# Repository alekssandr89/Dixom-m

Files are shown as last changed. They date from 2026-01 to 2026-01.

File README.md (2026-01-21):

# Dixom-m  
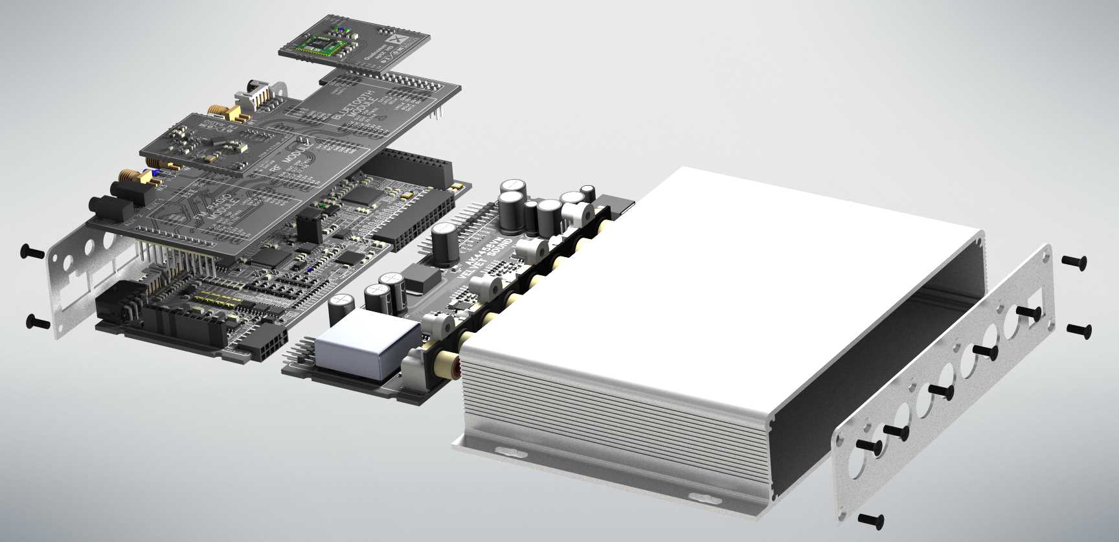
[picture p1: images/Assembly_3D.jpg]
Dixom-m Assembly 3D

## Цифровая модульная аудиоплатформа
<p align="center">
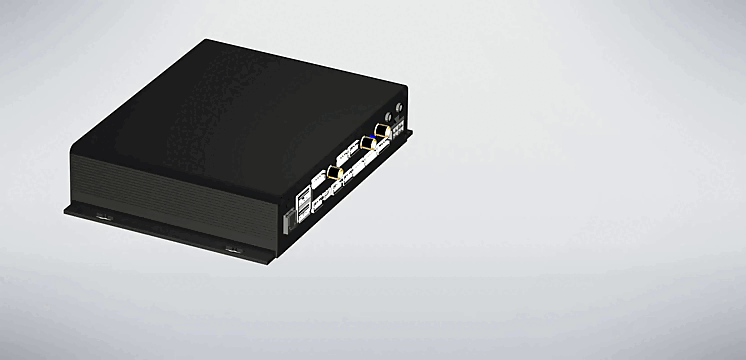
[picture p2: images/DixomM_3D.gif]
Dixom-m Assembly 3D
  
</p>

**Dixom-m** — это цифровая модульная аудиоплатформа, предназначенная в первую очередь для построения **кастомных автомобильных аудиосистем и автомагнитол** на базе **Android-планшетов и Android-устройств**. Платформа ориентирована на энтузиастов, разработчиков и интеграторов, которым требуется гибкая, расширяемая и качественная аудиоархитектура.

---

## Назначение платформы

Основная цель Dixom-m — предоставить аппаратную основу для создания **нестандартных Android-магнитол**, превосходящих по возможностям и качеству звучания серийные решения.

Платформа позволяет:
- использовать Android-планшет в качестве головного устройства (UI, навигация, мультимедиа);
- вынести аудиотракт в отдельные специализированные модули;
- масштабировать систему под конкретные требования проекта.

---

## Ключевая концепция

Dixom-m построена по **модульному принципу**, где каждый функциональный блок реализован в виде отдельного аппаратного модуля. Это обеспечивает:

- гибкость конфигурации;
- упрощённую модернизацию;
- возможность кастомизации под конкретный автомобиль и аудиосистему.

---

## Основные возможности

### Цифровая обработка аудиосигнала
- работа с цифровыми аудиопотоками;
- минимизация потерь качества;
- возможность интеграции DSP-алгоритмов.

### Модульная архитектура
- отдельные модули для:
  - аудиовходов и выходов;
  - усиления;
  - управления питанием;
  - коммутации и интерфейсов;
- возможность добавления новых модулей без переработки всей системы.

### Интеграция с Android
- совместимость с Android-планшетами и Android-устройствами;
- использование Android как центрального интерфейса управления;
- поддержка кастомных приложений и сервисов.

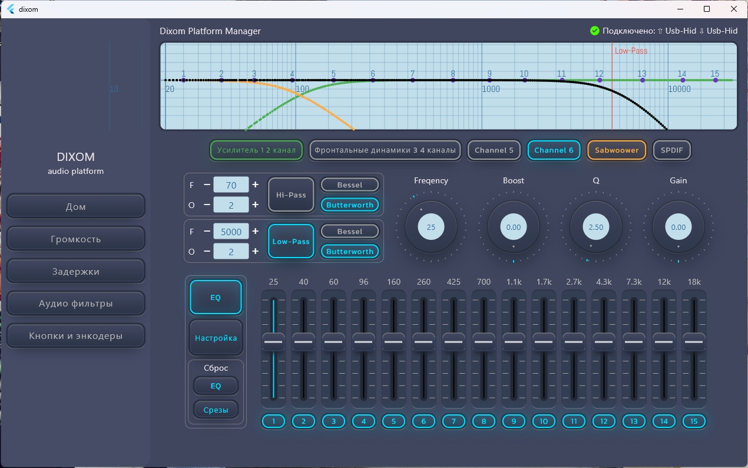
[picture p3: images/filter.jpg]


### Автомобильная направленность
- рассчитана на работу в автомобильной среде;
- возможность интеграции с бортовой сетью автомобиля;
- ориентация на качественный автозвук (SQ / SQL / кастомные проекты).

---

## Области применения

- кастомные Android-магнитолы;
- DIY-автозвук и инсталляции;
- экспериментальные аудиопроекты;
- прототипирование цифровых аудиосистем;
- мультимедийные автомобильные комплексы.

---

## Преимущества

- полная кастомизация под конкретный проект;
- независимость от готовых коммерческих магнитол;
- возможность постепенного расширения системы;
- ориентация на высокое качество звука;
- открытость к доработкам и развитию.

---

## Статус проекта

Проект **Dixom-m** находится в стадии активной разработки и развития.  
Архитектура, аппаратные модули и программная часть могут изменяться и дополняться.

---

## Цель проекта

Создание универсальной, масштабируемой и качественной аппаратной платформы для построения **современных автомобильных аудиосистем нового поколения** на базе Android.

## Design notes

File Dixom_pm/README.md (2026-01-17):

# dixom

A new Flutter project.

## Getting Started

This project is a starting point for a Flutter application.

A few resources to get you started if this is your first Flutter project:

- [Lab: Write your first Flutter app](https://docs.flutter.dev/get-started/codelab)
- [Cookbook: Useful Flutter samples](https://docs.flutter.dev/cookbook)

For help getting started with Flutter development, view the
[online documentation](https://docs.flutter.dev/), which offers tutorials,
samples, guidance on mobile development, and a full API reference.

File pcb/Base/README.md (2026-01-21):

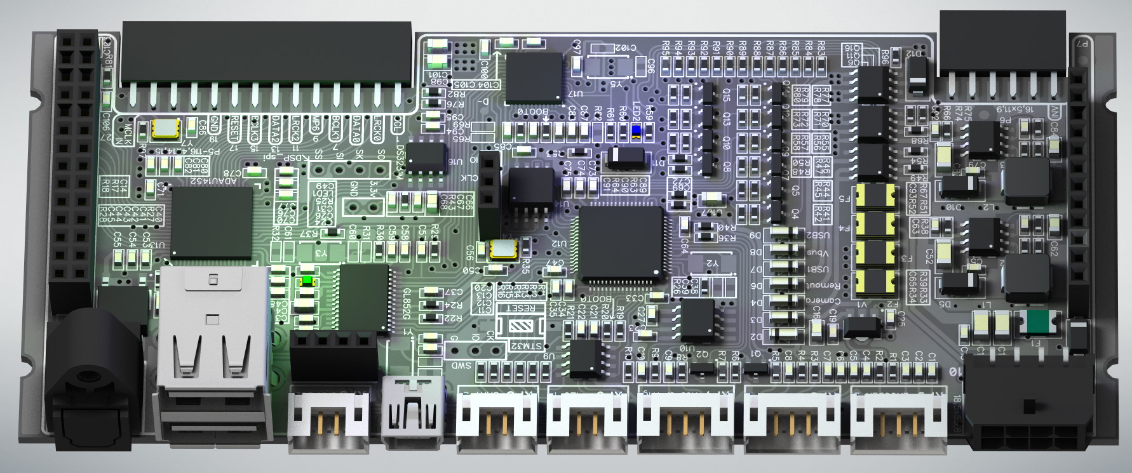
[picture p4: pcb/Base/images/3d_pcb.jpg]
3D PCB

**Рисунок 1 — 3D модель платы Dixom-M Base**

Для корректной сборки и запуска платформы необходимо приобрести все электронные компоненты, перечисленные в таблице № 1.

Рекомендуется закладывать резерв по пассивным компонентам в корпусе SMD 0603 (конденсаторы и резисторы), поскольку из-за их малых габаритов существует повышенный риск утери или повреждения в процессе ручного монтажа.

Компоненты, выделенные в таблице красным цветом, являются опциональными и не подлежат установке на базовую плату, соответственно их приобретение не требуется.
<details>
<summary><strong>Таблица 1 — Bill of Materials (BOM)</strong></summary>

<br>

| № | RefDes | Наименование | Корпус / Тип | Кол-во | Выводы |
|---|---|---|---|---|---|
| 1 | U9 | PCA82C250 | SOIC-8/150mil | 1 | 8 |
| 2 | U10 | 24LC256-I/SN | SOIC-8/150mil | 1 | 8 |
| 3 | U11 | GL852G-HHG12 | SOP-28/8.1x0.65 | 1 | 28 |
| 4 | U12 | STM32F405RGT6 | QFP-64/12x12x0.5 | 1 | 64 |
| 5 | U13 | ADAU1452WBCPZ | LFCSP-72 | 1 | 72 |
| 6 | U14 | W25Q80DVSSIG | SOIC-8/200mil | 1 | 8 |
| 7 | U15 | DS3231MZ | SOIC-8/150mil | 1 | 8 |
| 8 | U16 | STM32F411CEU6 | UFQFPN-48 (7x7) | 1 | 48 |
| 9 | V1 | HT7533-1 | SOT-89 | 1 | 3 |
|10 | V2, V3 | MP1584EN | SOIC-8EP/150mil | 2 | 8 |
|11 | D1, D5, D10–D12 | SS54B | SMB (DO-214AA) | 5 | 2 |
|12 | D2–D9 | LL4148 | LL-34 | 8 | 2 |
|13 | L1 | BCIHP0730-150M | IND 7×7×3 mm | 1 | 2 |
|14 | L2 | BCIHP0730-100M | IND 7×7×3 mm | 1 | 2 |
|15 | F1 | TLC-MSMD150/24 | 1812 | 1 | 2 |
|16 | F2 | TLC-MSMD110 | 1812 | 1 | 2 |
|17 | F3–F5 | TLC-MSMD110/24 | 1812 | 3 | 2 |
|18 | Q1, Q2, Q4, Q5, Q7–Q10, Q12–Q15 | BC817-40 | SOT-23 | 12 | 3 |
|19 | Q3 | STD2805T4 | DPAK-3 | 1 | 3 |
|20 | Q6, Q11, Q16 | AO4801 | SOIC-8/150mil | 3 | 8 |
|21 | Y4 | Q33310F70060700 (12 MHz) | SMD 3225-4P | 1 | 4 |
|22 | Y6 | SX7M24.576M20F30TNN | SMD 3225-4P | 1 | 4 |
|23 | Y7 | SX3M22.5792M20F30TNN | SMD 3225-4P | 1 | 4 |
|24 | LED1 | Зелёный светодиод | SMD 0603 | 1 | 2 |
|25 | LED2 | Синий светодиод | SMD 0603 | 1 | 2 |
|26 | C1, C2, C3, C5, C6, C7, C9, C10, C48, C53, C70, C80 | 10 nF | SMD 0603 | 12 | 2 |
|27 | C4, C8, C13, C19–C26, C28, C29, C33, C34, C37, C40, C42, C43, C45, C46, C49–C51, C54, C58, C59, C63, C64, C67, C71, C72, C74, C77–C79, C81, C85–C88, C91, C92, C94, C97, C103, C105 | 100 nF | SMD 0603 | 46 | 2 |
|28 | C14, C16, C30, C31, C62, C66, C84, C98, C101 | 22 µF 16 V | SMD 0805 | 9 | 2 |
|29 | C15, C22, C27, C35, C36, C44, C47, C55, C57, C68, C69, C73, C75, C76, C82, C89, C90, C95, C100, C104 | 1 µF | SMD 0603 | 20 | 2 |
|30 | C17, C18, C52, C83 | 22 µF 25 V | SMD 1206 | 4 | 2 |
|31 | C32 | 5.6 nF | SMD 0603 | 1 | 2 |
|32 | C41, C56, C65, C106 | 150 pF | SMD 0603 | 4 | 2 |
|33 | C93 | 220 pF | SMD 0603 | 1 | 2 |
|34 | R1, R3, R5, R7, R9, R10, R12, R21, R29, R41, R43, R44, R46, R48–R50, R54, R55, R57, R68, R70, R72, R74, R75, R77, R79, R96 | 10 kΩ | SMD 0603 | 27 | 2 |
|35 | R2, R4, R6, R8, R12–R16, R19, R20, R23, R24, R26, R35, R37, R42, R45, R47, R56, R58, R61, R71, R73, R78, R80, R81, R83–R88, R91, R97 | 100 Ω | SMD 0603 | 36 | 2 |
|36 | R11 | 120 Ω | SMD 0603 | 1 | 2 |
|37 | R17, R18, R76, R82, R90, R93, R95 | 2.2 kΩ | SMD 0603 | 7 | 2 |
|38 | R22, R25, R28, R36, R40, R53, R59, R60, R63, R64 | 1 kΩ | SMD 0603 | 10 | 2 |
|39 | R27 | 4.3 kΩ | SMD 0603 | 1 | 2 |
|40 | R33 | 20 kΩ | SMD 0603 | 1 | 2 |
|41 | R34 | 100 kΩ | SMD 0603 | 1 | 2 |
|42 | R38, R66 | 200 kΩ | SMD 0603 | 2 | 2 |
|43 | R39 | 3.9 kΩ | SMD 0603 | 1 | 2 |
|44 | R51 | 47 kΩ | SMD 0603 | 1 | 2 |
|45 | R52 | 68 kΩ | SMD 0603 | 1 | 2 |
|46 | R67, R89, R92, R94 | 15 kΩ | SMD 0603 | 4 | 2 |
|47 | CON1, CON2 | DS1023-2×14SF11 | P=2.54 mm | 2 | 28 |
|48 | CON6 | A2541HWV-3P | P=2.54 mm | 1 | 3 |
|49 | CON7 | C36191 | P=2.54 mm | 1 | 12 |
|50 | CON8 | A2541HWV-12P | P=2.54 mm | 1 | 12 |
|51 | CON9 | A2541HWV-4P | P=2.54 mm | 1 | 4 |
|52 | XP1 | PLR135/T9 | Through Hole | 1 | 3 |
|53 | XP2 | 907-112A1012D10200 | Plugin | 1 | 8 |
|54 | XP3, XP5, XP6 | S4B-PH-K-S | Push-Pull, P=2 mm | 3 | 4 |
|55 | XP4 | 920-462A2021D10102 | Plugin | 1 | 5 |
|56 | XP7–XP9 | S5B-PH-K-S | Push-Pull, P=2 mm | 1 | 5 |
|57 | XP10 | 43045-1200 | Micro-Fit | 1 | 8 |

</details>

Базовая плата аудио платформы Dixom-m выполнена на четырёхслойной печатной плате: верхний слой, два внутренних и нижний. Конструкция платы предусматривает размещение всех компонентов исключительно на верхней стороне, что значительно упрощает монтаж и последующую отладку устройства.

# Этапы сборки базовой платы аудио платформы Dixom-m

Процесс сборки базовой платы необходимо разделить на четыре этапа:

### Этап A — Монтаж и тестирование источников питания
- Необходимы напряжения **+3.3 В** и **+5 В**.
- Используются DC-DC преобразователи **MP1584EN** с регулировкой через сопротивления.
- Важно избегать повышения напряжения на линиях из-за ошибок или бракованных компонентов.
- Соберите и настройте источники питания.
- Проверьте стабильность +3.3 В и +5.0 В при входе 9–20 В.

### Этап B — Монтаж микросхем, микроконтроллеров и SMD-компонентов
### Этап C — Загрузка прошивок в микроконтроллеры
### Этап D — Комплексное тестирование собранной платы.
---

> **Важно:**  
> Устанавливать разъёмы и соединители следует только после успешного тестирования.  
> Ранний монтаж может осложнить замену неисправных компонентов во время отладки.

## A. Монтаж и тестирование источников питания

Для сборки DC-DC источников питания необходимы компоненты, перечисленные в таблице №2.  
На рисунке ниже зелёной областью схематически показано расположение этих компонентов.

Для подачи питания необходимо припаять системный разъём **XP10**.

Компоненты, выделенные красной зоной, на данном этапе устанавливать не нужно,  
за исключением резистора **R59** (SMD 0603, 1 кОм), который находится в красной зоне,  
он необходим для запуска DC-DC преобразователей.

После загрузки прошивки запуском и остановкой источников питания будет управлять микроконтроллер.
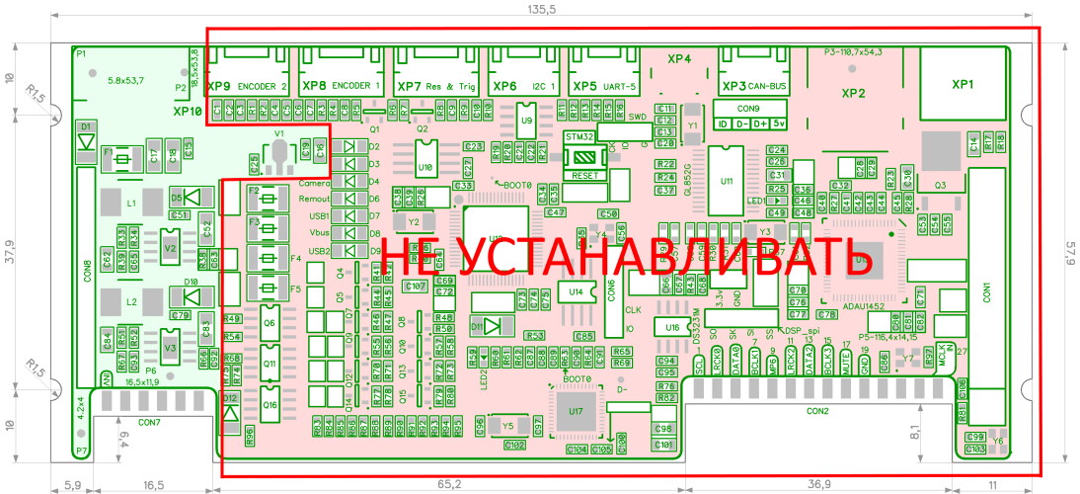
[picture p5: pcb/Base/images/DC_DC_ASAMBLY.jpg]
Рисунок 2 — Пайка источников питания

**Рисунок 2 — Пайка источников питания**

Для удобства ниже приведён список компонентов источников питания (эти позиции также присутствуют в Таблице 1).
<details>
<summary><strong>Таблица компонентов источника питания</strong></summary>

<br>

| №  | Обозначение | Наименование | Корпус | Кол-во | Выводы |
|-----|---|---|---|---|---|
| 1 | V1 | HT7533-1 | SOT89 | 1 | 3 |
| 2 | V2, V3 | MP1584EN | SOIC-8EP/150mil | 2 | 8 |
| 3 | D1, D5, D10 | SS54B | SMB(DO-214AA) | 3 | 2 |
| 4 | L1 | BCIHP0730-150M | IND 7*7*3mm | 1 | 2 |
| 5 | L2 | BCIHP0730-100M | IND 7*7*3mm | 1 | 2 |
| 6 | F1 | TLC-MSMD150/24 (24V 1.5A) | 1812 | 1 | 2 |
| 7 | C19, C25, C51, C63, C79, C92 | 100nF | SMD 0603 | 6 | 2 |
| 8 | C16, C62, C84 | 22uF 16V | SMD 0805 | 2 | 2 |
| 9 | C15 | 1uF | SMD 0603 | 1 | 2 |
| 10  | C65 | 150pF | SMD 0603 | 1 | 2 |
| 11  | C17, C18, C52, C83 | 22uF 25V | SMD 1206 | 4 | 2 |
| 12  | C93 | 220pF | SMD 0603 | 1 | 2 |
| 13  | R17, R18, R76, R82, R90, R93, R95 | 2.2kOm | SMD 0603 | 7 | 2 |
| 14  | R22, R25, R28, R36, R40, R53, R59, R60, R63, R64 | 1kOm | SMD 0603 | 10 | 2 |
| 15  | R33 | 20kOm | SMD 0603 | 1 | 2 |
| 16  | R34 | 100kOm | SMD 0603 | 1 | 2 |
| 17  | R38, R66 | 200kOm | SMD 0603 | 2 | 2 |
| 18  | R39 | 3.9kOm | SMD 0603 | 1 | 2 |
| 19  | R51 | 47kOm | SMD 0603 | 1 | 2 |
| 20  | R52 | 68kOm | SMD 0603 | 1 | 2 |
| 21  | R67 | 15kOm | SMD 0603 | 4 | 2 |
| 22  | XP10 | 43045-1200 | Micro Fit | 1 | 8 |

</details>

После завершения монтажа компонентов подайте напряжение в диапазоне от 9 до 20 В.  
Рекомендуется использовать лабораторный источник питания и проверить стабильность выходных напряжений по всему диапазону входных значений.

В первую очередь измерьте напряжение на конденсаторе **C16** — оно должно быть ровно **+3.3 В**.

Далее проверьте наличие напряжения на разъёме **CON2**. Здесь должны присутствовать напряжения **+3.3 В** и **+5.0 В**.  
Допустимые отклонения:  
- для +3.3 В — от 3.1 В до 3.4 В  
- для +5.0 В — от 4.7 В до 5.2 В  

Если напряжения выходят за эти пределы, необходимо найти и устранить причину.

Если на выходе DC-DC модулей (разъём CON2) напряжение отсутствует, проверьте наличие +3.3 В на резисторе **R59** с обеих сторон — он отвечает за включение преобразователей.  
Если напряжение на резисторе есть, проведите дополнительные проверки цепей вокруг микросхем MP1584 для выявления причины неисправности.

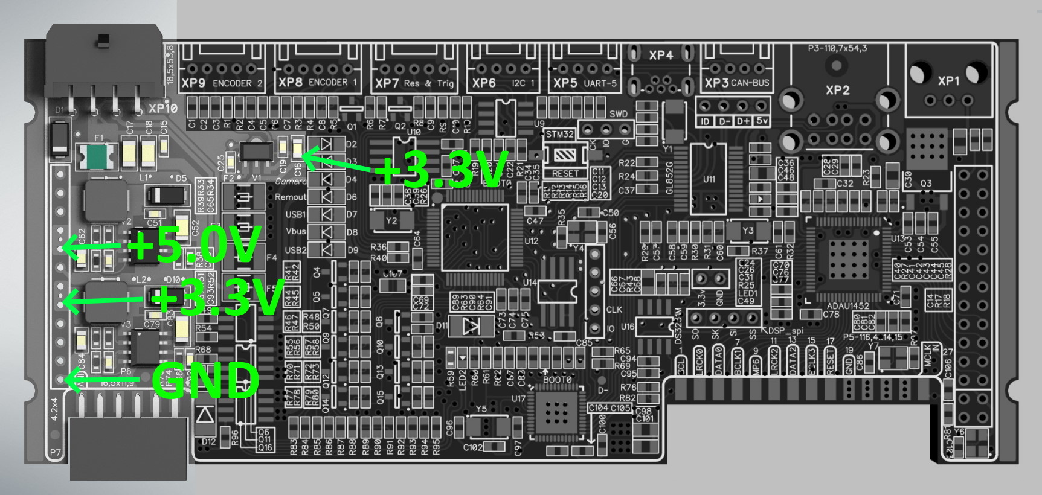
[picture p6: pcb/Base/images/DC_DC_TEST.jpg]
Рисунок 3 — Тестирование источников питания

**Рисунок 3 — Тестирование источников питания**

## B. Монтаж микросхем, микроконтроллеров и SMD-компонентов

После тщательной проверки всех напряжений и подтверждения их соответствия требованиям, можно приступать к монтажу остальных SMD-компонентов.

Ниже представлена схема расположения компонентов, а в таблице №1 — список компонентов с их позициями.  
В таблице компоненты, которые на данном этапе устанавливать не нужно, выделены красным цветом.  

Для удобства поиска компонентов в таблице доступен фильтр.

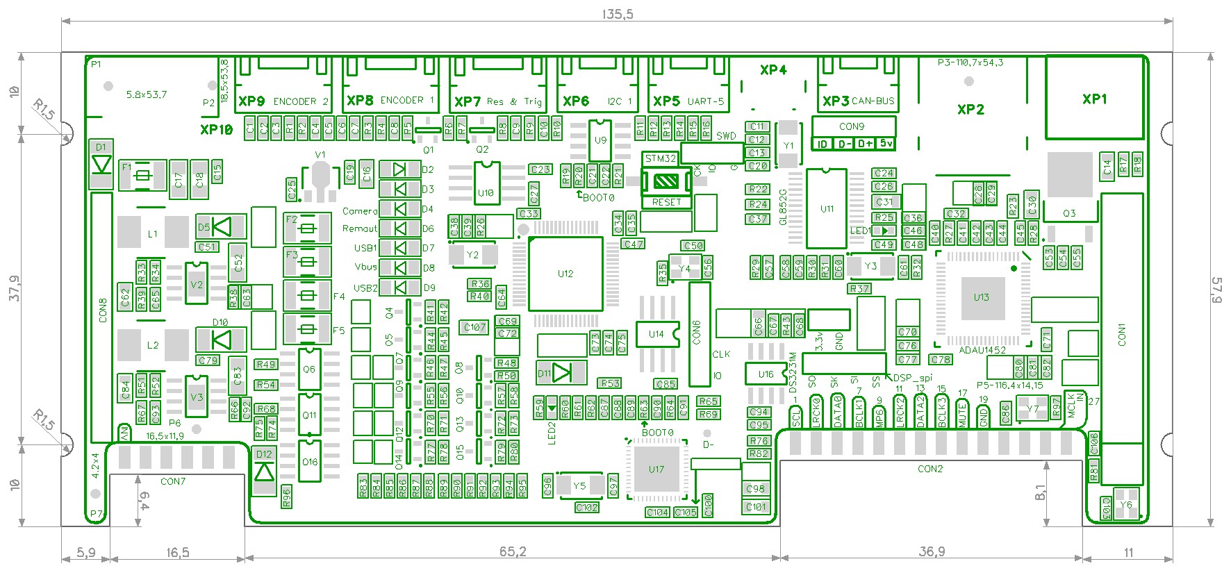
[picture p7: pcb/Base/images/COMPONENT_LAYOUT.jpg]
Рисунок 4 — Слой с компонентами

**Рисунок 4 — Слой с компонентами**
На данном этапе рекомендуется установить только минимальное количество разъёмов:  
основной разъём питания, MiniUSB-разъём и два соединителя — **CON2** и **CON7** для подключения ЦАП.  

Такой подход обусловлен тем, что при возникновении неисправностей в процессе загрузки прошивок и тестирования перепайка компонентов может занять много времени и потребовать усилий.  
Кроме того, использование паяльного фена повышает риск повреждения разъёмов и соединителей.

Ниже приведён рисунок, иллюстрирующий внешний вид печатной платы на данном этапе.

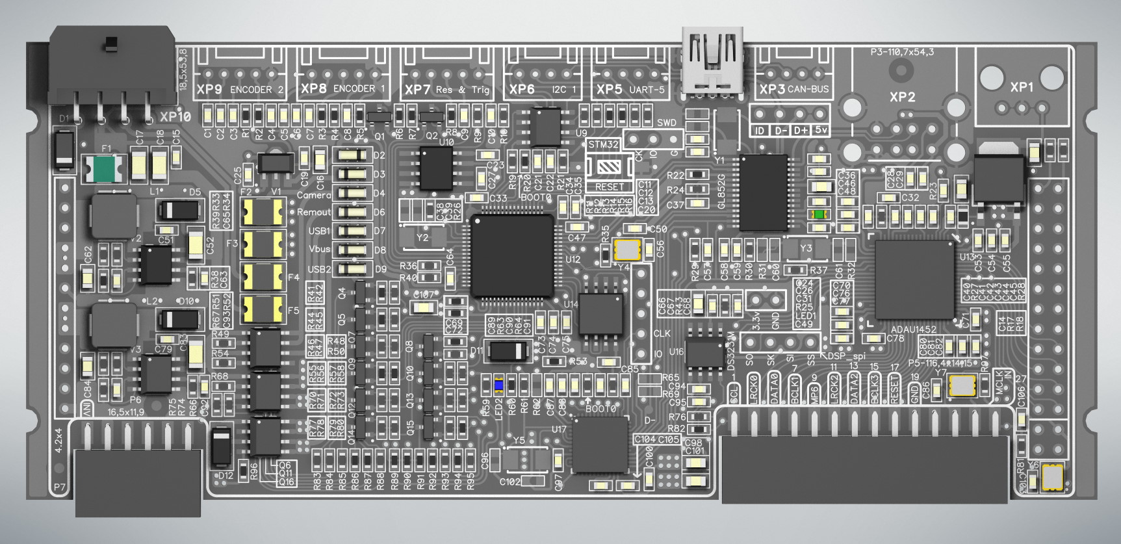
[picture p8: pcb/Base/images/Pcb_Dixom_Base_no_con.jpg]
Рисунок 5 — Плата без разъёмов

**Рисунок 5 — Плата без разъёмов**

## С Загрузка прошивок в микроконтроллеры и обновление

Для полноценной работы аудио платформы необходимо загрузить две прошивки:  
- одну в звуковую карту **STM32F411CEU6**,  
- вторую — в базовый микроконтроллер **STM32F405RGT6**.  

Существует два способа загрузки прошивок:  
1. Без программатора — через USB-кабель.  
2. С использованием программатора **ST-Link V2**, подключаясь к портам программирования SWD.

Для загрузки прошивок необходимо скачать соответствующие программы и файлы:  
- **Sound Bootloader** — включает загрузчик и основную прошивку звуковой карты.  
- **Base Bootloader** — содержит только загрузчик основного контроллера.

Чтобы загрузить основную прошивку:  
1. Сначала загрузите загрузчик в микроконтроллер **STM32F405RGT6**.  
2. Подключите аудио платформу к компьютеру через USB-кабель.  
3. Запустите программу **DixomPM**.  
4. Перейдите на вкладку **«Информация»**, нажмите кнопку **«Проверить наличие обновлений»** и загрузите обновление.  

> Для обновления требуется подключение к интернету.

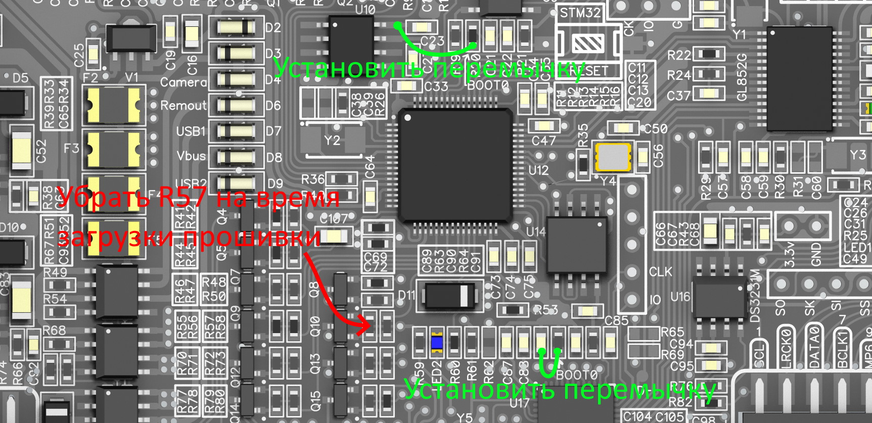
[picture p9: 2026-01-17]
pcb/Base/images/Pcb_Dixom_Base_dfu.jpg

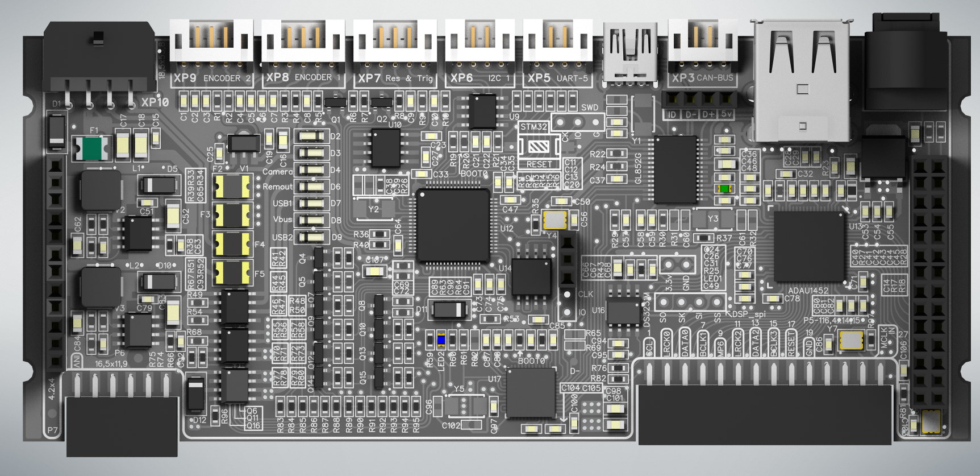
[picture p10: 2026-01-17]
pcb/Base/images/Pcb_Dixom_Base_Top.jpg

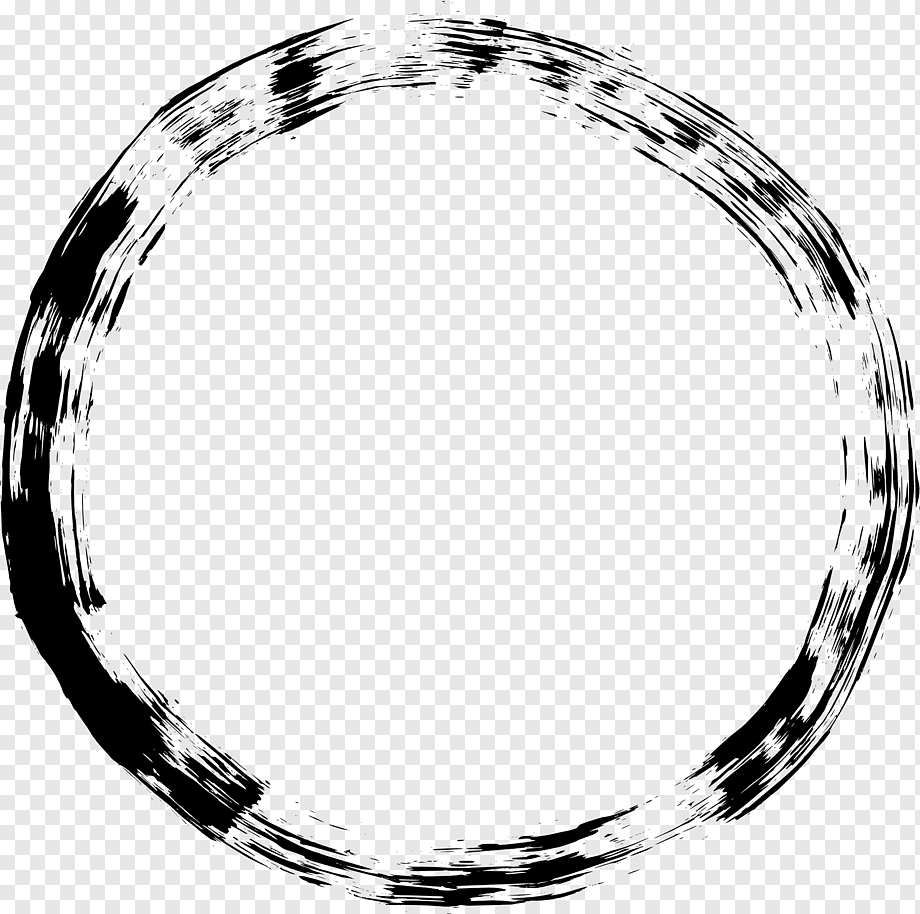
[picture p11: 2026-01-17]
Dixom_pm/assets/images/jpg/r1.png

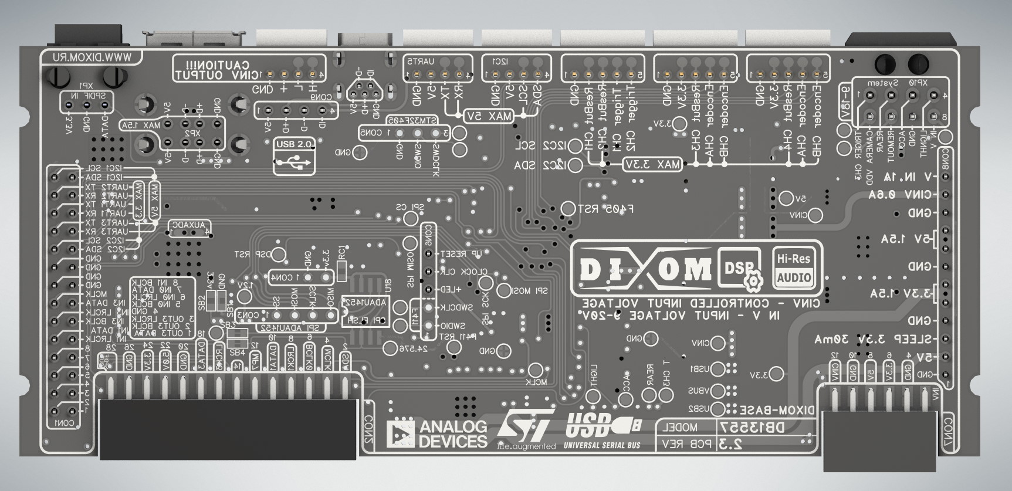
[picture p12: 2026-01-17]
pcb/Base/images/Pcb_Dixom_Base_Bottom.jpg

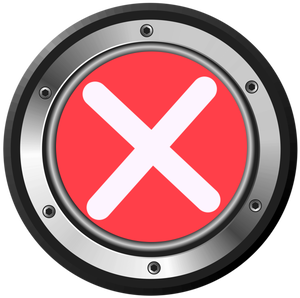
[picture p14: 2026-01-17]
Dixom_pm/assets/images/png/speakerMute.png

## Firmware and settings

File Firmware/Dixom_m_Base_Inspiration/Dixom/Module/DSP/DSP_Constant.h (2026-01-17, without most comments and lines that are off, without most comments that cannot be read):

#define __DSP_CONSTANT_H__
#include <Constants.h>
#define EQ_                         "EQ "
#define STATUS_EQ_                  "STATUS EQ "
#define CROSS_                      "CROSS "
#define PRESET_EQ_                  "PRESET EQ "
#define PRESET_CROSS_               "PRESET CROSS "
#define VOL_                        "VOL "
#define DELAY_                      "DELAY "
#define SOURCE_                     "SOURCE "
#define INVERT_                     "INVERT "
#define BTN_                        "BTN "
#define SETTINGS_                   "SETTINGS "
#define TIMER_                      "TIMER "
#define PHATSTEREO_                 "PHATSTEREO "
#define FILTR                       "FILTR"
#define ALL                         "ALL"
#define DATA_LENGTH_20            20
#define DATA_LENGTH_12            12
#define DATA_LENGTH_4             4
#define CONV_FLOAT                0.01
#define CONV_INT                  100
#define DacVolum                  0
#define MasterVolum               10
#define COUNT_USER_PRESET         4  //3 user preset + 1 main
#define PresetOff                 0
#define PresetUser1               1
#define PresetUser2               2
#define PresetUser3               3
#define PresetUser4               4
#define PresetUser5               5
#define PresetFlat                6
#define PresetBass                7
#define PresetBassExtreme         8
#define PresetBassAndHigh         9
#define PresetHigh                10
#define PresetClassic             11
#define PresetDancing             12
#define PresetRock                13
#define PresetTehno               14
#define PresetSpeaker             15
#define PresetLive                16
#define PresetMedium              17
#define PresetSoft                18
#define PresetSoftBass            19
#define PresetSoftHigh            20
#define GAIN_MIN                  -20
#define GAIN_MAX                  10
#define UNIQ_ELEM_CH_QE            15
typedef enum
{
	SoursUsb             =0,
	SoursBluetoooth      =1,
	SoursAux             =2,
	SoursRadio           =3,
	SoursSpdif           =4,
	SoursMic             =5
}TDE_SoundzSource;
typedef enum
{
	General_EQ =0,
	CH1        =1,
	CH2        =2,
	CH3        =3,
	CH4        =4,
	CH5        =5,
	CH6        =6,
	CH7        =7,
	CH8        =8,
	CH9        =9,
	CH10       =10,
	CH11       =11,
	CH12       =12,
	SPDIF_L    =13,
	SPDIF_R    =14
}TDE_AudioChanel;
typedef enum
{
	Band1 =0,
	Band2 =1,
	Band3 =2,
	Band4 =3,
	Band5 =4,
	Band6 =5,
	Band7 =6,
	Band8 =7,
	Band9 =8,
	Band10 =9,
	Band11 =10,
	Band12 =11,
	Band13 =12,
	Band14 =13,
	Band15 =14,
	Band16 =15,
	Band17 =16,
	Band18 =17,
	Band19 =18,
	Band20 =19,
	Band21 =20,
	Band22 =21,
	Band23 =22,
	Band24 =23,
	Band25 =24,
	Band26 =25,
	Band27 =26,
	Band28 =27,
	Band29 =28,
	Band30 =29
}TDE_EqBandNum;
typedef enum
{
	FILTER_OFF           =0,//GOOD
	PEAK                 =1,//GOOD
	LOWPASS              =2,//GOOD
	HIGHPASS             =3,//GOOD
	BUTTERWORTH_LP       =4,//GOOD
	BUTTERWORTH_HP       =5,//GOOD
	BESSEL_LP            =6,//GOOD
	BESSEL_HP            =7,//GOOD
	LOWPASS_FIRST        =8,//GOOD
	HIGHPASS_FIRST       =9,//GOOD
	LOW_SHELF            =10,//GOOD
	HIGH_SHELF           =11,//GOOD
	LINKWITZ_RILEY_HP    =12,//NO GOOD
	LINKWITZ_RILEY_LP    =13,//NO GOOD
	BANDPASS             =14,//NO GOOD
	BANDSTOP             =15//NO GOOD
}TDE_FilterType;
typedef enum
{
	High_Pass =0,
	Low_Pass  =1
}TDE_CrossoverFilterType;
typedef enum
{
	Main_Preset   =0,
	User_preset1  =1,
	User_preset2  =2,
	User_preset3  =3
}TDE_Preset;
typedef enum
{
	VolumControlOnDAC            =0,
	VolumControlOnDSP            =1,
	VolumControlOnLoudness       =2
}TDE_VolumeControlMode;
#define SAMPLE_RATE_22050         22050
#define SAMPLE_RATE_32000         32000
#define SAMPLE_RATE_44100         44100
#define SAMPLE_RATE_48000         48000
#define SAMPLE_RATE_88200         88200
#define SAMPLE_RATE_96000         96000
#define SAMPLE_RATE_192000        192000
#define SAMPLE_RATE_348000        348000
#define SAMPLE_RATE_768000        768000
#define GAIN_CONST                0
#define CrossoverCount            14
#define EqualizerCount            15
#define DELAY_SAMPLE              1440
#define FILTER_EQ_SOURCE_Q_DEF    71    //*0,01
#define FILTER_CROSS_Q_DEF        71    //*0,01
#define FILTER_EQ_CH_Q_DEF        250   //*0,01
#define FILTER_TYPE_DEF           1
#define FILTER_FREQ_DEF           20
#define FILTER_BOOST_DEF          0      //*0,01
#define FILTER_ORDER_DEF          2
#define FILTER_EQ_ONOFF_DEF       ON
#define FILTER_CROSS_ONOFF_DEF    OFF
#define FILTER_POINT_DEF          0
#define DEFAULT_INVERT            0
#define DEFAULT_DELAY             0     //*0,01
#define DEFAULT_GAIN              0
#define NUM_ELEM_EQ_GENERAL      30
#define NUM_ELEM_DELAY           14
#define NUM_ELEM_INVERT          26
#define NUM_ELEM_PHATSTEREO      6
#define NUM_ELEM_WIDESTEREO      6
#define NUM_ELEM_SUPPERBASS      6
#define NUM_ELEM_VOL             248
#define NUM_ELEM_FILTR           270
#define NUM_ELEM_EQ_CENTR        30
#define NUM_ELEM_CROSSOVER       14
#define NUM_ELEM_CROSSOVER_TYPE  2
#define NUM_ELEM_EQ_CH           14
#define NUM_ELEM_GROUP           8
#define NUM_PRESET               3
#define NUM_ELEM_EQ_CH_BAND      15
#define NUM_ELEM_EQ_SOURCE_BAND  5
#define NUM_ELEM_DAC             13
#define NUM_ELEM_LOUDNESS        6
#define NUM_ELEM_LIMITER         14
#define NUM_ELEM_GAIN            14
#define NUM_ELEM_GROUP_NAME      7
#define NUM_ELEM_GROUP_DELAY     7
#define NUM_ELEM_LVL_DETECTED    64
#define NUM_ELEM_GRAPHIC_EQ      32
#define NUM_ELEM_DSP_SETTINGS    64
#define NUM_ELEM_SOURCE          6
#define NUM_ELEM_VOL_EEPROM      50
#define INVERT_MIN                0
#define INVERT_MAX                1
#define DELAY_MAX                 1000
#define DELAY_MIN                 0
#define VOL_MAX                   60
#define VOL_MIN                   0
#define FREQ_MAX                  22000
#define FREQ_MIN                  20
#define Q_MAX                     3000     //*0.01 = 30.00
#define Q_MIN                     5        //*0.01 = 00.05
#define BOOST_MAX                 2000     //*0.01 = 20.00
#define BOOST_MIN                 -2000    //*0.01 =-20.00
#define NAME_MAX_LEN              48
#define SBASSFREQ_MIN             20
#define SBASSFREQ_MAX             500
#define SBASSLVL_MIN              1
#define SBASSLVL_MAX              30
#define SBASSINTESIV_MIN          1
#define SBASSINTESIV_MAX          30
#define NO_GROUP                  255
#define ORDER_MAX                 10
#define ORDER_MIN                 1
#define SOUND_DELAY_MAX           3000
#define SOUND_DELAY_MIN           0
#define WIDESTEREO_MIN            0
#define WIDESTEREO_MAX            20
#define DEF_SINGEN_FREQ           1500
#define DEF_SINGEN_PHASE          0
#define EQ_GENERAL                0
#define FILTR_CH1                 1
#define FILTR_CH2                 2
#define FILTR_CH3                 3
#define FILTR_CH4                 4
#define FILTR_CH5                 5
#define FILTR_CH6                 6
#define FILTR_CH7                 7
#define FILTR_CH8                 8
#define FILTR_CH9                 9
#define FILTR_CH10                10
#define FILTR_CH11                11
#define FILTR_CH12                12
#define FILTR_SPDIFL              13
#define FILTR_SPDIFR              14
#define CrossCH1                  15
#define CrossCH2                  16
#define CrossCH3                  17
#define CrossCH4                  18
#define CrossCH5                  19
#define CrossCH6                  20
#define CrossCH7                  21
#define CrossCH8                  22
#define CrossCH9                  23
#define CrossCH10                 24
#define CrossCH11                 25
#define CrossCH12                 26
#define CrossSPDIFL               27
#define CrossSPDIFR               28
#define CROSS_ORDER_1             1
#define CROSS_ORDER_2             2
#define CROSS_ORDER_3             3
#define CROSS_ORDER_4             4
#define CROSS_ORDER_5             5
#define CROSS_ORDER_6             6
#define CROSS_ORDER_7             7
#define CROSS_ORDER_8             8
#define CROSS_ORDER_9             9
#define CROSS_ORDER_10            10
#define MaxVolumUsb               0
#define MaxVolumBluetooth         1
#define MaxVolumAux               2
#define MaxVolumRadio             3
#define MinVolumMic               4
#define MinVolumUsb               5
#define MinVolumBluetooth         6
#define MinVolumAux               7
#define MinVolumRadio             8
#define MinVolumSpdif             9
#define VolumUsb                  11
#define VolumBluetooth            14
#define VolumAux                  17
#define VolumRadio                20
#define VolumSpdif                23
#define VolumSoursMic             126
#define VolumGroup1               29
#define VolumGroup2               32
#define VolumGroup3               35
#define VolumGroup4               38
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

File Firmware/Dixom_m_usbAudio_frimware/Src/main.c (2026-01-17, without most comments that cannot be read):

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
/* Includes ------------------------------------------------------------------*/
#include "main.h"

/* USER CODE BEGIN Includes */
#include "usbd_audio_core.h"
#include "usbd_usr.h"
#include "usb_conf.h"
#include "usb_core.h"
#include "SoundMenu.h"
/* USER CODE END Includes */

I2C_HandleTypeDef hi2c1;
DMA_HandleTypeDef hdma_i2c1_rx;
DMA_HandleTypeDef hdma_i2c1_tx;

I2S_HandleTypeDef hi2s2;
DMA_HandleTypeDef hdma_spi2_tx;

TIM_HandleTypeDef htim2;

void SystemClock_Config(void);
static void MX_GPIO_Init(void);
static void MX_DMA_Init(void);
static void MX_I2C1_Init(void);
static void MX_I2S2_Init(void);
static void MX_TIM2_Init(void);
static void MX_NVIC_Init(void);
/* USER CODE BEGIN 0 */

static void Sound_MX_TIM2_Init(void);
#define APPLICATION_ADDRESS    0x08004000

__ALIGN_BEGIN USB_OTG_CORE_HANDLE  USB_OTG_dev __ALIGN_END;
/* USER CODE END 0 */

/**
  * @brief  The application entry point.
  * @retval int
  */
int main(void)
{
  /* USER CODE BEGIN 1 */
	__disable_irq();
	SCB->VTOR = APPLICATION_ADDRESS;
	__enable_irq();
  /* USER CODE END 1 */

  /* MCU Configuration--------------------------------------------------------*/

  /* Reset of all peripherals, Initializes the Flash interface and the Systick. */
  HAL_Init();

  /* Configure the system clock */
  SystemClock_Config();

  /* Initialize all configured peripherals */
  MX_GPIO_Init();
  MX_DMA_Init();
  MX_I2C1_Init();
  MX_I2S2_Init();
 // MX_TIM2_Init();

  /* Initialize interrupts */
  MX_NVIC_Init();
  /* USER CODE BEGIN 2 */
  HAL_I2S_MspInit(&hi2s2);

  Sound_MX_TIM2_Init();

  TIM2->CR1 |= (uint32_t)TIM_CR1_CEN;

  Init_Sound_Param();

  USBD_Init(&USB_OTG_dev,
 	            USB_OTG_FS_CORE_ID,
 	            &USR_desc,
 	            &AUDIO_cb,
 	            &USR_cb);

  I2C_1_START_IRQHandler();

  /* USER CODE END 2 */

  /* Infinite loop */
  /* USER CODE BEGIN WHILE */
  while (1)
  {
    /* USER CODE END WHILE */

    /* USER CODE BEGIN 3 */
  }
  /* USER CODE END 3 */
}

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
/* USER CODE BEGIN 4 */

/**
  * @brief TIM2 Initialization Function
  * @param None
  * @retval None
  */
static void Sound_MX_TIM2_Init(void) {
	uint32_t temp;
	GPIO_InitTypeDef GPIO_InitStruct;


	GPIO_InitStruct.Pin = GPIO_PIN_0;
	GPIO_InitStruct.Mode = GPIO_MODE_AF_PP;
	GPIO_InitStruct.Pull = GPIO_NOPULL;
	GPIO_InitStruct.Speed = GPIO_SPEED_FREQ_HIGH;
	GPIO_InitStruct.Alternate = GPIO_AF1_TIM2;
	HAL_GPIO_Init(GPIOA, &GPIO_InitStruct);

	__HAL_RCC_TIM2_CLK_ENABLE()
	;

	TIM_HandleTypeDef htim2;

	htim2.Instance = TIM2;
	htim2.Init.Prescaler = 0;
	htim2.Init.CounterMode = TIM_COUNTERMODE_UP;
	htim2.Init.Period = 0xffffffff;
	htim2.Init.ClockDivision = 0;
	htim2.Init.RepetitionCounter = 0;
	if (HAL_TIM_Base_Init(&htim2) != HAL_OK) {
		Error_Handler();
	}

	temp = TIM2->SMCR;
	temp &= (uint32_t) 0x00ff;
	TIM2->SMCR = temp;
	TIM2->SMCR |= TIM_SMCR_ECE;

	/* Disable the Channel 1: Reset the CC1E Bit */
	TIM2->CCER &= (uint32_t) ~TIM_CCER_CC1E;

	temp = TIM2->CCMR1;
	/* Select the Input and set the filter */
	temp &= ((uint32_t) ~TIM_CCMR1_CC1S) & ((uint32_t) ~TIM_CCMR1_IC1F);
	temp |= (uint32_t) (TIM_CCMR1_CC1S);
	/* Write to TIM2 CCMR1 register */
	TIM2->CCMR1 = temp;

	temp = TIM2->CCER;
	/* Select the Polarity and set the CC1E Bit */
	temp &= (uint32_t) ~(TIM_CCER_CC1P | TIM_CCER_CC1NP);
	temp |= (uint32_t) (TIM_CCER_CC1E);
	/* Write to TIM2 CCER register */
	TIM2->CCER = temp;

	/* Reset the IC1PSC Bits */
	TIM2->CCMR1 &= (uint32_t) ~TIM_CCMR1_IC1PSC;

	/* Set the Timer remapping configuration */
	TIM2->OR = (uint32_t) 0x0800;

	/* Get the TIM2 SMCR register value */
	temp = TIM2->SMCR;
	/* Reset the TS Bits */
	temp &= (uint32_t) ~TIM_SMCR_TS;
	/* Set the Input Trigger source */
	temp |= TIM_TS_ITR1;
	/* Write to TIM2 SMCR */
	TIM2->SMCR = temp;

	/* Reset the SMS Bits */
	TIM2->SMCR &= (uint32_t) ~TIM_SMCR_SMS;
	/* Select the Slave Mode */
	TIM2->SMCR |= (uint32_t) 0x0004; //TIM_SlaveMode_Reset
}


/* USER CODE END 4 */
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


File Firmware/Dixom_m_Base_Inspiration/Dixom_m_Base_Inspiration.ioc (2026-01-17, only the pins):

Mcu.UserName=STM32F405RGTx
PA0-WKUP.GPIO_Label=WakeUP
PA0-WKUP.Signal=SYS_WKUP
PA1.GPIO_Label=ADC_CH4
PA1.Signal=ADCx_IN1
PA10.Signal=USART1_RX
PA11.Signal=USB_OTG_FS_DM
PA12.Signal=USB_OTG_FS_DP
PA13.Signal=SYS_JTMS-SWDIO
PA14.Signal=SYS_JTCK-SWCLK
PA15.GPIO_Label=OTG
PA15.Signal=GPIO_Output
PA2.Signal=USART2_TX
PA3.Signal=USART2_RX
PA4.GPIO_Label=ADC_CH3
PA4.Signal=ADCx_IN4
PA5.GPIO_Label=VDD_CINV
PA5.Signal=GPIO_Output
PA6.GPIO_Label=ADC_LIGHT
PA6.Signal=ADCx_IN6
PA7.GPIO_Label=VDD_5V_USB1
PA7.Signal=GPIO_Output
PA8.GPIO_Label=Modules_Reset
PA8.Signal=GPIO_Output
PA9.Signal=USART1_TX
PB0.GPIO_Label=VDD_5V_Vbus
PB0.Signal=GPIO_Output
PB1.GPIO_Label=DC_DC_Power
PB1.Signal=GPIO_Output
PB10.Signal=I2C2_SCL
PB11.Signal=I2C2_SDA
PB12.GPIO_Label=SPI_CS_EEPROM
PB12.Signal=GPIO_Output
PB13.Signal=SPI2_SCK
PB14.Signal=SPI2_MISO
PB15.Signal=SPI2_MOSI
PB2.GPIO_Label=LED
PB2.Signal=GPIO_Output
PB3.GPIO_Label=DAC_RESET
PB3.Signal=GPIO_Output
PB4.GPIO_Label=ENCODER2_CHB
PB4.Signal=S_TIM3_CH1
PB5.GPIO_Label=ENCODER2_CHA
PB5.Signal=S_TIM3_CH2
PB6.Signal=I2C1_SCL
PB7.Signal=I2C1_SDA
PB8.Signal=CAN1_RX
PB9.Signal=CAN1_TX
PC0.GPIO_Label=ADC_CH1
PC0.Signal=ADCx_IN10
PC1.GPIO_Label=ADC_CH2
PC1.Signal=ADCx_IN11
PC10.Signal=USART3_TX
PC11.Signal=USART3_RX
PC12.Signal=UART5_TX
PC13-ANTI_TAMP.GPIO_Label=VDD_Remot
PC13-ANTI_TAMP.Signal=GPIO_Output
PC14-OSC32_IN.GPIO_Label=Rear_Detected
PC14-OSC32_IN.Signal=GPIO_Input
PC15-OSC32_OUT.GPIO_Label=VDD_Camera
PC15-OSC32_OUT.Signal=GPIO_Output
PC2.GPIO_Label=GND_Triger_CH1
PC2.Signal=GPIO_Output
PC3.GPIO_Label=GND_Triger_CH2
PC3.Signal=GPIO_Output
PC4.GPIO_Label=ADC_ACC
PC4.Signal=ADCx_IN14
PC5.GPIO_Label=VDD_5V_USB2
PC5.Signal=GPIO_Output
PC6.GPIO_Label=ENCODER1_CHB
PC6.Signal=S_TIM8_CH1
PC7.GPIO_Label=ENCODER1_CHA
PC7.Signal=S_TIM8_CH2
PC8.GPIO_Label=SPI_CS_DSP
PC8.Signal=GPIO_Output
PC9.GPIO_Label=GND_Triger_CH3
PC9.Signal=GPIO_Output
PD2.Signal=UART5_RX
PH0-OSC_IN.Signal=RCC_OSC_IN
PH1-OSC_OUT.Signal=RCC_OSC_OUT

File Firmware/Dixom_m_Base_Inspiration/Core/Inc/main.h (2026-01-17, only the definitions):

#define VDD_Remot_Pin GPIO_PIN_13
#define VDD_Remot_GPIO_Port GPIOC
#define Rear_Detected_Pin GPIO_PIN_14
#define Rear_Detected_GPIO_Port GPIOC
#define VDD_Camera_Pin GPIO_PIN_15
#define VDD_Camera_GPIO_Port GPIOC
#define ADC_CH1_Pin GPIO_PIN_0
#define ADC_CH1_GPIO_Port GPIOC
#define ADC_CH2_Pin GPIO_PIN_1
#define ADC_CH2_GPIO_Port GPIOC
#define GND_Triger_CH1_Pin GPIO_PIN_2
#define GND_Triger_CH1_GPIO_Port GPIOC
#define GND_Triger_CH2_Pin GPIO_PIN_3
#define GND_Triger_CH2_GPIO_Port GPIOC
#define WakeUP_Pin GPIO_PIN_0
#define WakeUP_GPIO_Port GPIOA
#define ADC_CH4_Pin GPIO_PIN_1
#define ADC_CH4_GPIO_Port GPIOA
#define ADC_CH3_Pin GPIO_PIN_4
#define ADC_CH3_GPIO_Port GPIOA
#define VDD_CINV_Pin GPIO_PIN_5
#define VDD_CINV_GPIO_Port GPIOA
#define ADC_LIGHT_Pin GPIO_PIN_6
#define ADC_LIGHT_GPIO_Port GPIOA
#define VDD_5V_USB1_Pin GPIO_PIN_7
#define VDD_5V_USB1_GPIO_Port GPIOA
#define ADC_ACC_Pin GPIO_PIN_4
#define ADC_ACC_GPIO_Port GPIOC
#define VDD_5V_USB2_Pin GPIO_PIN_5
#define VDD_5V_USB2_GPIO_Port GPIOC
#define VDD_5V_Vbus_Pin GPIO_PIN_0
#define VDD_5V_Vbus_GPIO_Port GPIOB
#define DC_DC_Power_Pin GPIO_PIN_1
#define DC_DC_Power_GPIO_Port GPIOB
#define LED_Pin GPIO_PIN_2
#define LED_GPIO_Port GPIOB
#define SPI_CS_EEPROM_Pin GPIO_PIN_12
#define SPI_CS_EEPROM_GPIO_Port GPIOB
#define ENCODER1_CHB_Pin GPIO_PIN_6
#define ENCODER1_CHB_GPIO_Port GPIOC
#define ENCODER1_CHA_Pin GPIO_PIN_7
#define ENCODER1_CHA_GPIO_Port GPIOC
#define SPI_CS_DSP_Pin GPIO_PIN_8
#define SPI_CS_DSP_GPIO_Port GPIOC
#define GND_Triger_CH3_Pin GPIO_PIN_9
#define GND_Triger_CH3_GPIO_Port GPIOC
#define Modules_Reset_Pin GPIO_PIN_8
#define Modules_Reset_GPIO_Port GPIOA
#define OTG_Pin GPIO_PIN_15
#define OTG_GPIO_Port GPIOA
#define DAC_RESET_Pin GPIO_PIN_3
#define DAC_RESET_GPIO_Port GPIOB
#define ENCODER2_CHB_Pin GPIO_PIN_4
#define ENCODER2_CHB_GPIO_Port GPIOB
#define ENCODER2_CHA_Pin GPIO_PIN_5
#define ENCODER2_CHA_GPIO_Port GPIOB

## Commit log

2026-01-19 Добавлены gerebr файлы для печатных плат
    [1_LayerTop.gbr, 1_LayerTopMask.gbr, 1_LayerTopPMask.gbr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]
2026-02-19 Добавлен .gitignore, удалены папки Debug и .settings
2026-02-19 Выпущена прошивка версии 5.010

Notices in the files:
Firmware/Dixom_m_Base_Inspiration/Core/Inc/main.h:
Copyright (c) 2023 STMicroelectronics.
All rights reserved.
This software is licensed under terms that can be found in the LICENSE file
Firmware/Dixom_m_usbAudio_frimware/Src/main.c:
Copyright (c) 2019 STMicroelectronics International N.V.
